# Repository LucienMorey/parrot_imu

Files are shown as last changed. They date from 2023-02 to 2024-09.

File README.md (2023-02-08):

# parrot_imu

## Purpose

This design will host an IMU board for the Parody tripedal robotic platform. It will expose connect an IMU to the teensy 4.1 microcontroller with the ability to deliver this data over CAN bus and over an ethernet connection.

## TODOs

### Power Subsystem

Take a 24 V input and reduce it to supplies for powering the associated subsystems.

- [x] 5v supply - tentatitvely [VR10S05](https://www.digikey.com.au/en/products/detail/xp-power/VR10S05/13147713)
- [x] 3.3v supply - tentatitvely [TR05S3V3](https://www.digikey.com.au/en/products/detail/xp-power/TR05S3V3/4488636)
- [x] add terminal to supply power input. probably one of thosegreen terminals that can fit a ferule or a wago terminal [panel mount xt30](https://www.ebay.com.au/itm/393171351901)
- [x] Is it worth bothering with reverse polarity protection? Just a shottkey diode? Nope. just added a gendered connector to prevent this.
- [x] debugging LEDS to indicate presense of power
  - [x] at input line
  - [x] after 5v supply
  - [x] after 3.3V supply
- [x] calculate resitors for power leds

Q. what is an LDO and will it suffice or is a proper dc/dc converter required?

A. They both do the same thing with regard to switching direct current voltages. DC/DC converters are more efficent but more suspetable to noise because they use fets and things that generate switching noise. LDOS are less efficient and will have some current drop depending on the load drawn from the supply. An LDO will work in this scenario and they are cheaper so I will probably go for that. Tony recommended dcdc converter so switching

### Can Transeiver

One potential mechanism for delivering IMU data to the robot comms network. This is the back up option because it cannot interface directly to the ros network. It does not require FD functionality for higher bit rates but this option will be made available if a component can be sourced.

- [x] Pick a can trasniever that can interface with the teensy - picked the [TJA1441AT/0Z](https://www.digikey.com.au/en/products/detail/nxp-usa-inc/TJA1441AT-0Z/13691175). This shouldnt be an issue because it provides both 5v VCC and a seperate VIO input that I can specify the 3.3v logic level required for the teensy
- [x] create footprint and symbol
- [x] add optional termination points
- [x] Add a proper screw terminal or similar mechanism to make adding to the can bus easy [scrw terminal here](https://www.digikey.com.au/en/products/detail/cui-devices/TB005-762-02BE/10064113)
- [ ] Add proper Silk screen markers to indicate CAN-H/L so things are easy

### Ethernet Jack

Intended to be the primary mechanism for delivering imu data to the robot comms network. This is known to beable to interface directly with the ros network through microros on udp transports.

- [x] Find an approppriate RJ45 magjack connector - Currently the [SI-60062-F](https://www.digikey.com.au/en/products/detail/bel-fuse-inc/SI-60062-F/1033372)
- [x] Wire the connector to the teensy. note to follow the schematic outlined on thier magjack page found [here](https://www.pjrc.com/store/ethernet_kit.html). This should be as simple as just adding a capacitor and joining the pins but double check the smc design to be sure.
- [ ] Find link to small pins for ethernet

### Teensy 4.1

Primary microcontroller for interfacing with the IMU.

- [x] obtain premade footprint
- [ ] remember different pin styles for ethernet and general gpio
- [x] spi connection avoiding pin 13 so that ethernet can be used

### IMU

- [x] create symbol
- [x] create footprint
- [x] connect to SPI2 or 3 to avoid collision with ethernet
- [ ] Place footprint of breakout board
- [ ] double check if this should be i2c instead of spi
- [ ] check if interrupt pin or other functionality is going to be helpful

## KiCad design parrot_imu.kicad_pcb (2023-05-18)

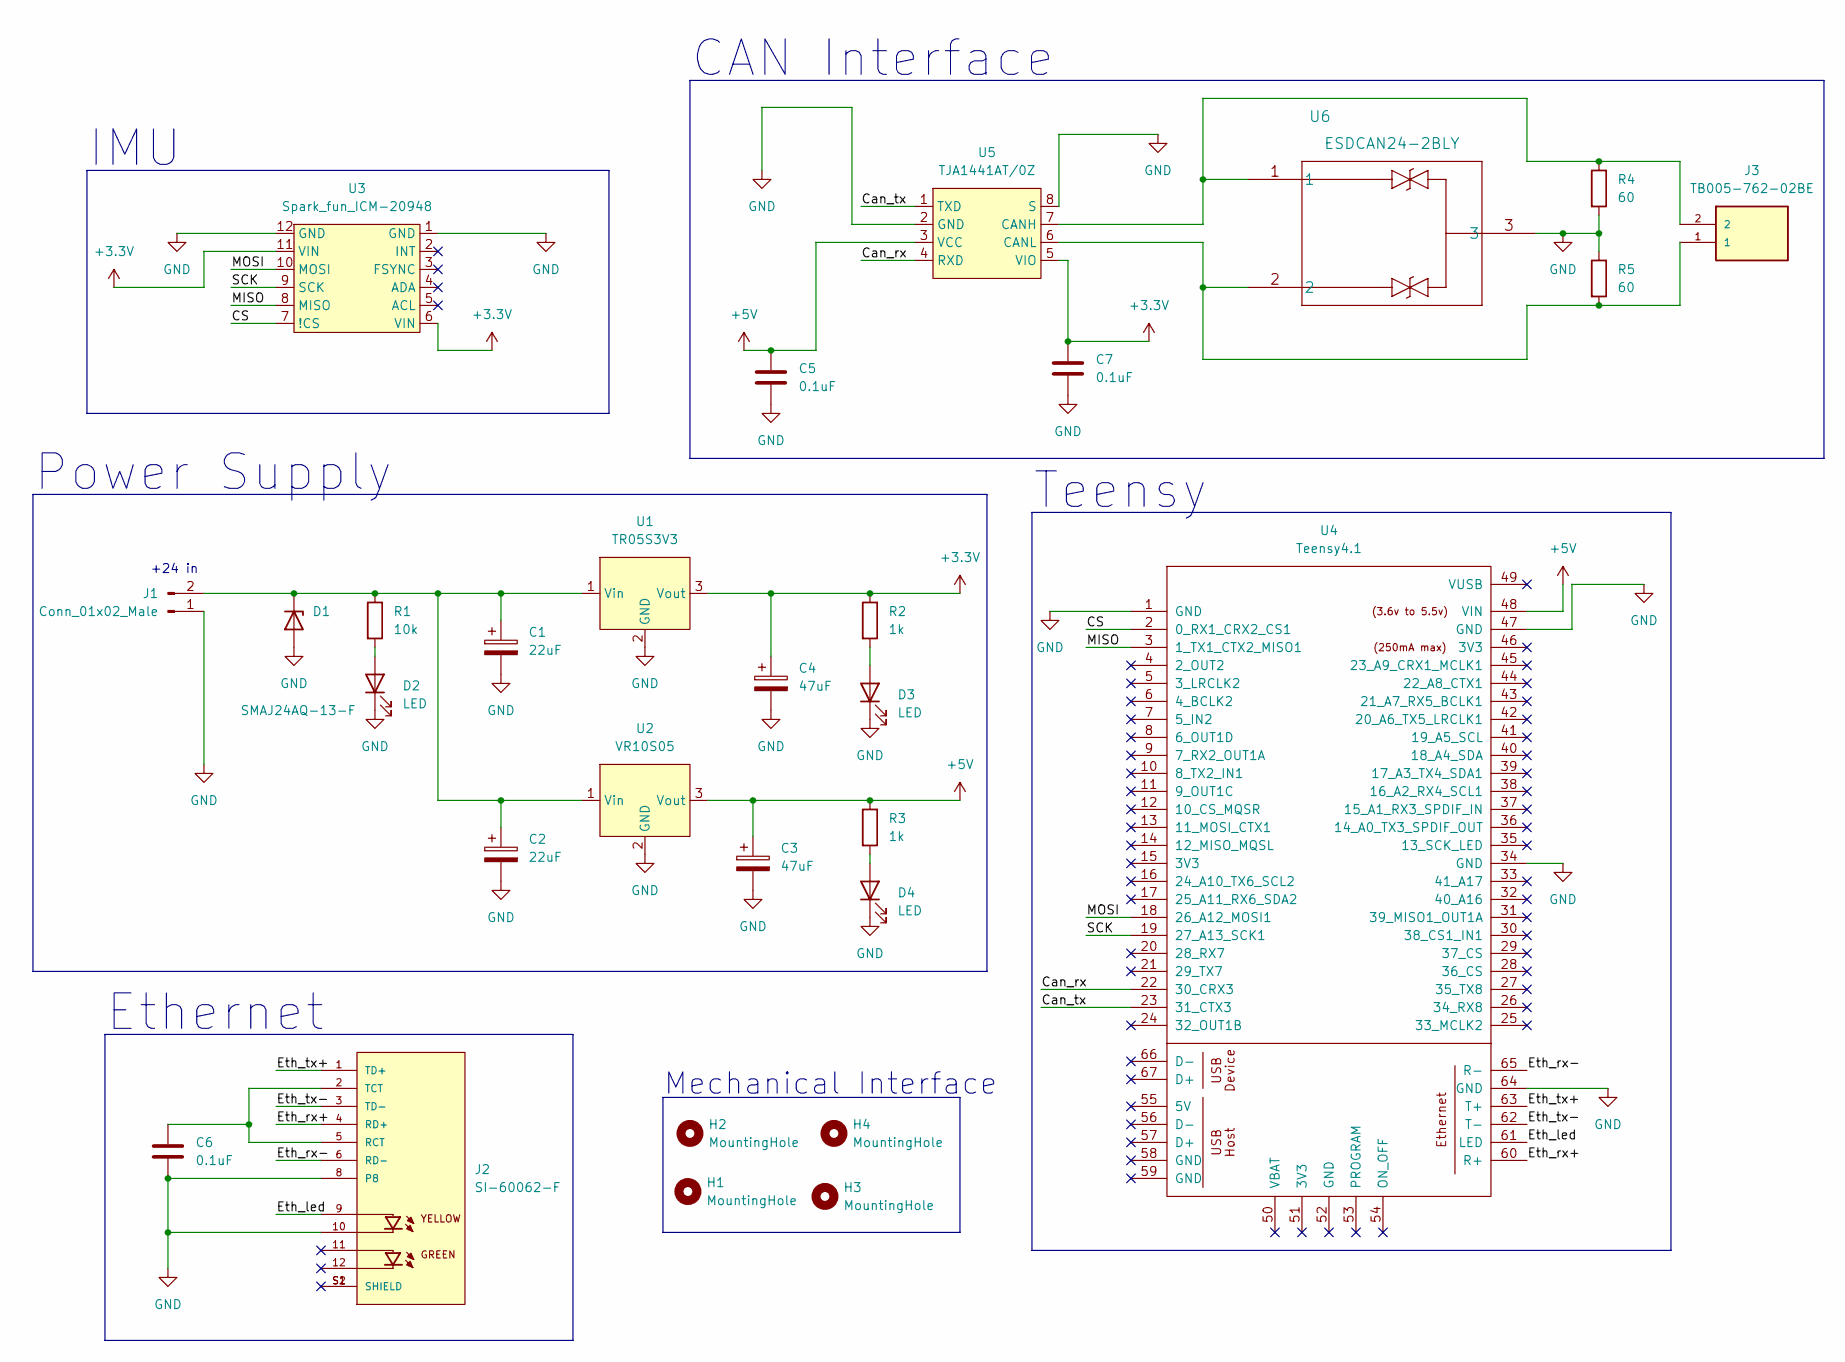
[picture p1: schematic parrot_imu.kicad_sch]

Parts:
C1, C2: 22uF; CP_Radial_D5.0mm_P2.00mm; Digikey 732-8857-1-ND
C3, C4: 47uF; CP_Radial_D6.3mm_P2.50mm; Digikey 732-8859-1-ND
C5, C6, C7: 0.1uF; C_0603_1608Metric; Digikey 1276-1935-1-ND
D1: SMAJ24AQ-13-F
D2, D3, D4: LED; LED_0603_1608Metric; Digikey 3147-B1911USD-20D000114U1930CT-ND
H1, H2, H3, H4: MountingHole; MountingHole_3.2mm_M3
J1: Conn_01x02_Male; AMASS_XT30PW-M_1x02_P2.50mm_Horizontal
J2: SI-60062-F; BEL_SI-60062-F; PARTREV B0
J3: TB005-762-02BE; CUI_TB005-762-02BE; Digikey 102-6189-ND
R1: 10k; R_0603_1608Metric; Digikey RNCP0603FTD10K0CT-ND
R2, R3: 1k; R_0603_1608Metric; Digikey RNCP0603FTD1K00CT-ND
R4, R5: 60; R_0603_1608Metric; Digikey 311-60.4HRCT-ND
U1: TR05S3V3; Digikey 1470-2257-5-ND
U2: VR10S05; Digikey 1470-VR10S05-ND
U3: Spark_fun_ICM-20948; Spark_fun_ICM-20498
U4: Teensy4.1; Teensy41
U5: TJA1441AT/0Z; SO-8_3.9x4.9mm_P1.27mm; Digikey 568-TJA1441AT/0ZCT-ND
U6: ESDCAN24-2BLY

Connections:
+3.3V: C4.1, C7.1, R2.1, U1.3 (Vout), U3.6 (VIN), U3.11 (VIN), U5.5 (VIO)
+5V: C3.1, C5.1, R3.1, U2.3 (Vout), U4.48 (VIN), U5.3 (VCC)
/CS: U3.7 (!CS), U4.2 (0_RX1_CRX2_CS1)
/Can_rx: U4.22 (30_CRX3), U5.4 (RXD)
/Can_tx: U4.23 (31_CTX3), U5.1 (TXD)
/Eth_led: J2.9, U4.61 (LED)
/Eth_rx+: J2.4 (RD+), U4.60 (R+)
/Eth_rx-: J2.6 (RD-), U4.65 (R-)
/Eth_tx+: J2.1 (TD+), U4.63 (T+)
/Eth_tx-: J2.3 (TD-), U4.62 (T-)
/MISO: U3.8 (MISO), U4.3 (1_TX1_CTX2_MISO1)
/MOSI: U3.10 (MOSI), U4.18 (26_A12_MOSI1)
/SCK: U3.9 (SCK), U4.19 (27_A13_SCK1)
GND: C1.2, C2.2, C3.2, C4.2, C5.2, C6.2, C7.2, D1.2 (A), D2.1 (K), D3.1 (K), D4.1 (K), J1.1, J2.8, J2.10, R4.2, R5.1, U1.2 (GND), U2.2 (GND), U3.1 (GND), U3.12 (GND), U4.1 (GND), U4.34 (GND), U4.47 (GND), U4.64 (GND), U5.2 (GND), U5.8 (S), U6.3
unnamed: C1.1, C2.1, D1.1 (K), J1.2, R1.1, U1.1 (Vin), U2.1 (Vin)
unnamed: C6.1, J2.2 (TCT), J2.5 (RCT)
unnamed: D2.2 (A), R1.2
unnamed: D3.2 (A), R2.2
unnamed: D4.2 (A), R3.2
unnamed: J3.1, R5.2, U5.6 (CANL), U6.2
unnamed: J3.2, R4.1, U5.7 (CANH), U6.1

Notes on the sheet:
Power Supply
CAN Interface
IMU
Mechanical Interface
Ethernet
Teensy
+24 in

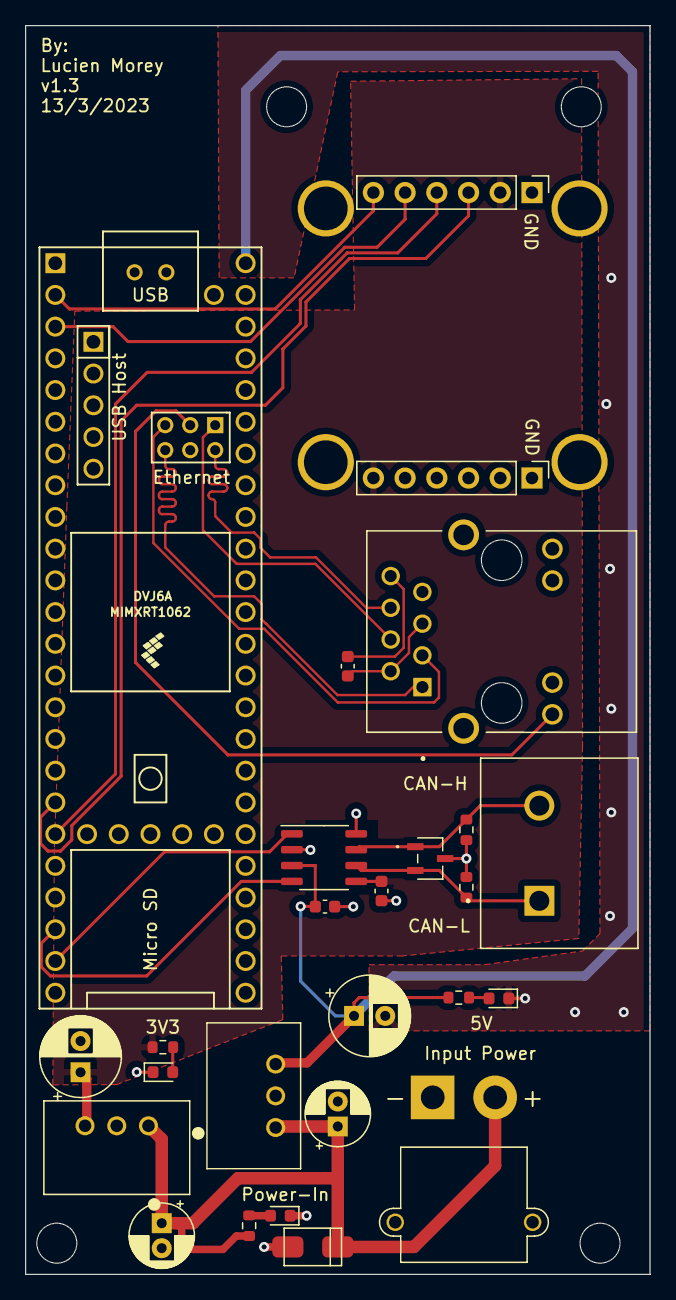
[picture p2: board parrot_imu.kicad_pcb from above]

Board: 2 copper layers, 50.0 x 100.0 mm, 29 parts (0 on the bottom side), 21 nets.

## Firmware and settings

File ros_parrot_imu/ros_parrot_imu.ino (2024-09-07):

#include <micro_ros_arduino.h>

#include "ICM_20948.h"
#include "SPI.h"
#include "constants.h"

#include <stdio.h>
#include <rcl/rcl.h>
#include <rcl/error_handling.h>
#include <rclc/rclc.h>
#include <rclc/executor.h>

#include <sensor_msgs/msg/imu.h>

rcl_publisher_t publisher;
sensor_msgs__msg__Imu msg;
rclc_support_t support;
rcl_allocator_t allocator;
rcl_node_t node;

// network setting variables
// Agent IP should be changed once used on real hardware to match network
const String AGENT_IP = "192.168.10.40";
const String CLIENT_IP = "192.168.10.10";
const int AGENT_PORT = 8888;
IPAddress client_ip;
IPAddress agent_ip;
// check if this can also be done based on the teensy ID
const byte MAC[] = {0x02, 0x47, 0x00, 0x00, 0x00, 0x01};

#define CS_PIN 0 // Which pin you connect CS to. Used only when "USE_SPI" is defined
#define LED_PIN 13

#define RCCHECK(fn)              \
  {                              \
    rcl_ret_t temp_rc = fn;      \
    if ((temp_rc != RCL_RET_OK)) \
    {                            \
      error_loop();              \
    }                            \
  }
#define RCSOFTCHECK(fn)          \
  {                              \
    rcl_ret_t temp_rc = fn;      \
    if ((temp_rc != RCL_RET_OK)) \
    {                            \
    }                            \
  }

void error_loop()
{
  while (1)
  {
    digitalWrite(LED_PIN, !digitalRead(LED_PIN));
    delay(100);
  }
}

ICM_20948_SPI myICM;

void setup()
{
  client_ip.fromString(CLIENT_IP);
  agent_ip.fromString(AGENT_IP);
  // set ethernet as the ros transport
  set_microros_native_ethernet_udp_transports(MAC, client_ip, agent_ip, AGENT_PORT);

  delay(2000);

  Serial.begin(9600);

  pinMode(LED_PIN, OUTPUT);
  digitalWrite(LED_PIN, HIGH);

  SPI1.begin();
}

bool init_node_interfaces(void)
{

  bool success = true;

  allocator = rcl_get_default_allocator();

  // create init_options
  if (rclc_support_init(&support, 0, NULL, &allocator) != RCL_RET_OK)
  {
    success = false;
    Serial.printf("Failed to init ROS2 support\n");
  }

  if ((success == true) && (rclc_node_init_default(&node, "teensy_imu_node", "", &support)))
  {
    success = false;
    Serial.printf("Failed to init ROS2 node\n");
  }

  if ((success == true) && (rclc_publisher_init_default(
                               &publisher,
                               &node,
                               ROSIDL_GET_MSG_TYPE_SUPPORT(sensor_msgs, msg, Imu),
                               "teensy_imu_data")))
  {
    success = false;
    Serial.printf("Failed to init ROS2 publisher\n");
  }

  memset(&msg, 0, sizeof(sensor_msgs__msg__Imu));

  return success;
}

void destroy_node_interfaces(void)
{
  rcl_publisher_fini(&publisher, &node);
  rcl_node_fini(&node);
  rclc_support_fini(&support);
}

bool configure_imu(void)
{
  bool initialized = false;
  while (!initialized)
  {

    // Initialize the ICM-20948
    // If the DMP is enabled, .begin performs a minimal startup. We need to configure the sample mode etc. manually.
    myICM.begin(CS_PIN, SPI1);

    if (myICM.status != ICM_20948_Stat_Ok)
    {
      delay(500);
      digitalWrite(LED_PIN, !digitalRead(LED_PIN));
    }
    else
    {
      initialized = true;
    }
  }

  bool success = true;

  if (myICM.initializeDMP() != ICM_20948_Stat_Ok)
  {
    success = false;
    Serial.printf("Failure to initialise IMU DMP\n");
  }

  // Enable the required sensors
  if ((success == true) && (myICM.enableDMPSensor(INV_ICM20948_SENSOR_ORIENTATION) != ICM_20948_Stat_Ok))
  {
    success = false;
    Serial.printf("Failure to enable orientation sensor\n");
  }

  if ((success == true) && (myICM.enableDMPSensor(INV_ICM20948_SENSOR_GYROSCOPE) != ICM_20948_Stat_Ok))
  {
    success = false;
    Serial.printf("Failure to enable gyroscope sensor\n");
  }

  if ((success == true) && (myICM.enableDMPSensor(INV_ICM20948_SENSOR_ACCELEROMETER) != ICM_20948_Stat_Ok))
  {
    success = false;
    Serial.printf("Failure to enable accelerometer sensor\n");
  }

  // Configure the output data rate for each of the sensors
  // this should configure them to each run at the max speed
  if ((success == true) && (myICM.setDMPODRrate(DMP_ODR_Reg_Quat9, 0) != ICM_20948_Stat_Ok))
  {
    success = false;
    Serial.printf("Failure to configure orientation output data rate\n");
  }
  if ((success == true) && (myICM.setDMPODRrate(DMP_ODR_Reg_Accel, 0) != ICM_20948_Stat_Ok))
  {
    success = false;
    Serial.printf("Failure to configure accelerometer output data rate\n");
  }
  if ((success == true) && (myICM.setDMPODRrate(DMP_ODR_Reg_Gyro, 0) != ICM_20948_Stat_Ok))
  {
    success = false;
    Serial.printf("Failure to configure gyroscope output data rate\n");
  }

  ICM_20948_fss_t myFSS;
  myFSS.a = gpm8;
  myFSS.g = dps250;

  if ((success == true) && (myICM.setFullScale((ICM_20948_Internal_Acc | ICM_20948_Internal_Gyr), myFSS) != ICM_20948_Stat_Ok))
  {
    success = false;
    Serial.printf("Failure to set scale for Accelerometer and Gyroscope\n");
  }

  // Enable the FIFO
  if ((success == true) && (myICM.enableFIFO() != ICM_20948_Stat_Ok))
  {
    success = false;
    Serial.printf("Failure to enable FIFO\n");
  }

  // Enable the DMP
  if ((success == true) && (myICM.enableDMP() != ICM_20948_Stat_Ok))
  {
    success = false;
    Serial.printf("Failure to enable DMP\n");
  }

  // Reset DMP
  if ((success == true) && (myICM.resetDMP() != ICM_20948_Stat_Ok))
  {
    success = false;
    Serial.printf("Failure to reset DMP\n");
  }

  // Reset FIFO
  if ((success == true) && (myICM.resetFIFO() != ICM_20948_Stat_Ok))
  {
    success = false;
    Serial.printf("Failure to reset FIFO\n");
  }

  return success;
}

void loop()
{

  bool success = true;
  success = init_node_interfaces();

  if ((success == true) && (!configure_imu()))
  {
    success = false;
    Serial.printf("Failure to configure the imu\n");
  }

  while (success == true)
  {

    icm_20948_DMP_data_t data;
    myICM.readDMPdataFromFIFO(&data);

    if ((myICM.status == ICM_20948_Stat_Ok) || (myICM.status == ICM_20948_Stat_FIFOMoreDataAvail))
    {
      if ((data.header & DMP_header_bitmap_Quat9) > 0) // We have asked for orientation data so we should receive Quat9
      {
        // Q0 value is computed from this equation: Q0^2 + Q1^2 + Q2^2 + Q3^2 = 1.
        // In case of drift, the sum will not add to 1, therefore, quaternion data need to be corrected with right bias values.
        // The quaternion data is scaled by 2^30.
        // Scale to +/- 1

        msg.orientation.x = ((double)data.Quat9.Data.Q1) * ORIENTATION_CONVERSION_FACTORS::QUATERNION_9_DOF; // Convert to double. Divide by 2^30
        msg.orientation.y = ((double)data.Quat9.Data.Q2) * ORIENTATION_CONVERSION_FACTORS::QUATERNION_9_DOF; // Convert to double. Divide by 2^30
        msg.orientation.z = ((double)data.Quat9.Data.Q3) * ORIENTATION_CONVERSION_FACTORS::QUATERNION_9_DOF; // Convert to double. Divide by 2^30
        msg.orientation.w = sqrt(1.0 - ((msg.orientation.x * msg.orientation.x) + (msg.orientation.y * msg.orientation.y) + (msg.orientation.z * msg.orientation.z)));
      }

      if ((data.header & DMP_header_bitmap_Accel) > 0) // We have asked for acceleration so we should receive raw accel
      {
        msg.linear_acceleration.x = (float)data.Raw_Accel.Data.X * ACCEL_CONVERSION_FACTORS::ACEEL_8G * GRAVITY;
        msg.linear_acceleration.y = (float)data.Raw_Accel.Data.Y * ACCEL_CONVERSION_FACTORS::ACEEL_8G * GRAVITY;
        msg.linear_acceleration.z = (float)data.Raw_Accel.Data.Z * ACCEL_CONVERSION_FACTORS::ACEEL_8G * GRAVITY;
      }

      if ((data.header & DMP_header_bitmap_Gyro) > 0) // We have asked angular velocity so we should receive raw gyro
      {
        msg.angular_velocity.x = (float)data.Raw_Gyro.Data.X * GYRO_CONVERSION_FACTORS::GYRO_250_DPS * PI / 180.0;
        msg.angular_velocity.y = (float)data.Raw_Gyro.Data.Y * GYRO_CONVERSION_FACTORS::GYRO_250_DPS * PI / 180.0;
        msg.angular_velocity.z = (float)data.Raw_Gyro.Data.Z * GYRO_CONVERSION_FACTORS::GYRO_250_DPS * PI / 180.0;
      }
    }

    if (rcl_publish(&publisher, &msg, NULL) != RCL_RET_OK)
    {
      success = false;
    }
  }

  destroy_node_interfaces();
}

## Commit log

2023-02-01 created basic kicad project
    [parrot_imu.kicad_pcb, parrot_imu.kicad_sch]
2023-02-01 added libraries for teensy
2023-02-01 added teensy to schematic
    [parrot_imu.kicad_sch]
2023-02-01 added ethernet jack symbol
    [parrot_imu.kicad_sch]
2023-02-01 added digikey part number to ethernet part
    [parrot_imu.kicad_sch]
2023-02-02 created footprint and symbol for ldo
    [parrot_imu.kicad_sch]
2023-02-03 created symbol and linked footprint for can transciever
2023-02-03 tweak to symbols and added imu breakout footprint/symbol
2023-02-03 added ics to schematic
    [parrot_imu.kicad_sch]
2023-02-03 some progress on the schematic and notes on other things to handle
    [parrot_imu.kicad_sch]
2023-02-06 added connector library
2023-02-06 dcdc supply footprints and symbols
2023-02-06 schematic done pre review
    [parrot_imu.kicad_sch]
2023-02-06 added notes and digikey part numbers
    [parrot_imu.kicad_sch]
2023-02-06 design review with tony
    [parrot_imu.kicad_sch]
2023-02-08 added tvs diodes to schematic
    [parrot_imu.kicad_sch]
2023-02-08 switched to xt30 connector and added leds for power
    [parrot_imu.kicad_sch]
2023-02-08 filled in footprints and digikey id for most parts
    [parrot_imu.kicad_sch]
2023-02-22 added missing footprint for can protection and imported parts to pcb design
    [parrot_imu.kicad_pcb, parrot_imu.kicad_sch]
2023-02-22 sort out errors with footprints and add mounting holes
    [parrot_imu.kicad_pcb, parrot_imu.kicad_sch]
2023-02-22 start of laying out components
    [parrot_imu.kicad_pcb, parrot_imu.kicad_sch]
2023-02-22 most of pcb and some steps
    [parrot_imu.kicad_pcb, parrot_imu.kicad_sch]
2023-02-22 completed draft pcb and added model for imu
    [parrot_imu.kicad_pcb, parrot_imu.kicad_sch]
2023-02-22 fix unconnected plane error
    [parrot_imu.kicad_pcb]
2023-02-22 fix errors with unconnected components
    [parrot_imu.kicad_pcb]
2023-02-23 removed trace between shield on ethernet
    [parrot_imu.kicad_pcb]
2023-02-23 dump of progress
    [parrot_imu.kicad_pcb, parrot_imu.kicad_sch]
2023-02-23 pcb redesign
    [parrot_imu.kicad_pcb, parrot_imu.kicad_sch]
2023-02-26 added step file for ethernet
    [parrot_imu.kicad_pcb]
2023-02-26 readded xt30 step model
    [parrot_imu.kicad_pcb]
2023-02-26 silk screen stuff
    [parrot_imu.kicad_pcb]
2023-02-27 add tony fixes from design review
    [parrot_imu.kicad_pcb]
2023-05-18 update pcb
    [parrot_imu.kicad_pcb, parrot_imu.kicad_sch]

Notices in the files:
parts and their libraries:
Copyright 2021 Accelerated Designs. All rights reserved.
